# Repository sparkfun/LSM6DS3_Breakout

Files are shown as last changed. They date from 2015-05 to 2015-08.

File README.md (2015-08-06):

SparkFun <PRODUCT NAME>
========================================

LSM6DS3 Breakout

[*LSM6DS3 Breakout (SEN-13339)*](https://www.sparkfun.com/products/13339)

The LSM6DS3 Breakout board allows easy connection to the LSM6DS3.

The LSM6DS3 is a accelerometer, gyroscope, and temperature sensor with embedded functions targeted at cellphones.  It can do high sample rates and includes an 8kB FIFO buffer for burst reads.

Repository Contents
-------------------

* **/Documentation** - Data sheets, additional product information
* **/Hardware** - Eagle design files (.brd, .sch)
* **/Libraries** - Libraries for use with the LSM6DS3 Breakout
* **/Production** - Production panel files (.brd)

Documentation
--------------
* **[Library](https://github.com/sparkfun/SparkFun_LSM6DS3_Arduino_Library)** - C++ library for the LSM6DS3 Breakout.
* **[Hookup Guide](https://learn.sparkfun.com/tutorials/lsm6ds3-breakout-hookup-guide)** - Basic hookup guide for the LSM6DS3 Breakout.

Product Versions
----------------
* [SEN-13339](https://www.sparkfun.com/products/13339)- LSM6DS3 Breakout board

Version History
---------------
* [V_1.0.0](https://github.com/sparkfun/LSM6DS3_Breakout/releases/tag/V_1.0.0) - Initial product release repository
* [V_0.3.0](https://github.com/sparkfun/LSM6DS3_Breakout/releases/tag/V_0.3.0) - HW version 0.3 release

License Information
-------------------

This product is _**open source**_! 

Please review the LICENSE.md file for license information. 

If you have any questions or concerns on licensing, please contact techsupport@sparkfun.com.

Distributed as-is; no warranty is given.

- Your friends at SparkFun.

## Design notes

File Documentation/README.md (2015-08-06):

SparkFun Documentation
=======================

File List
---------

* AN4650_DM00157511.pdf - LSM6DS3 application note
* class diagrams.odg - src class diagrams
* class diagrams.pdf - export class diagrams
* DM00133076.pdf - LSM6DS3 datasheet
* Layout_CD00134799.pdf LSM6DS3 footprint information
* README.md - This file
* Test Plan.odt - description of things to test before release
* Test Record.odt - Results and findings of HW test

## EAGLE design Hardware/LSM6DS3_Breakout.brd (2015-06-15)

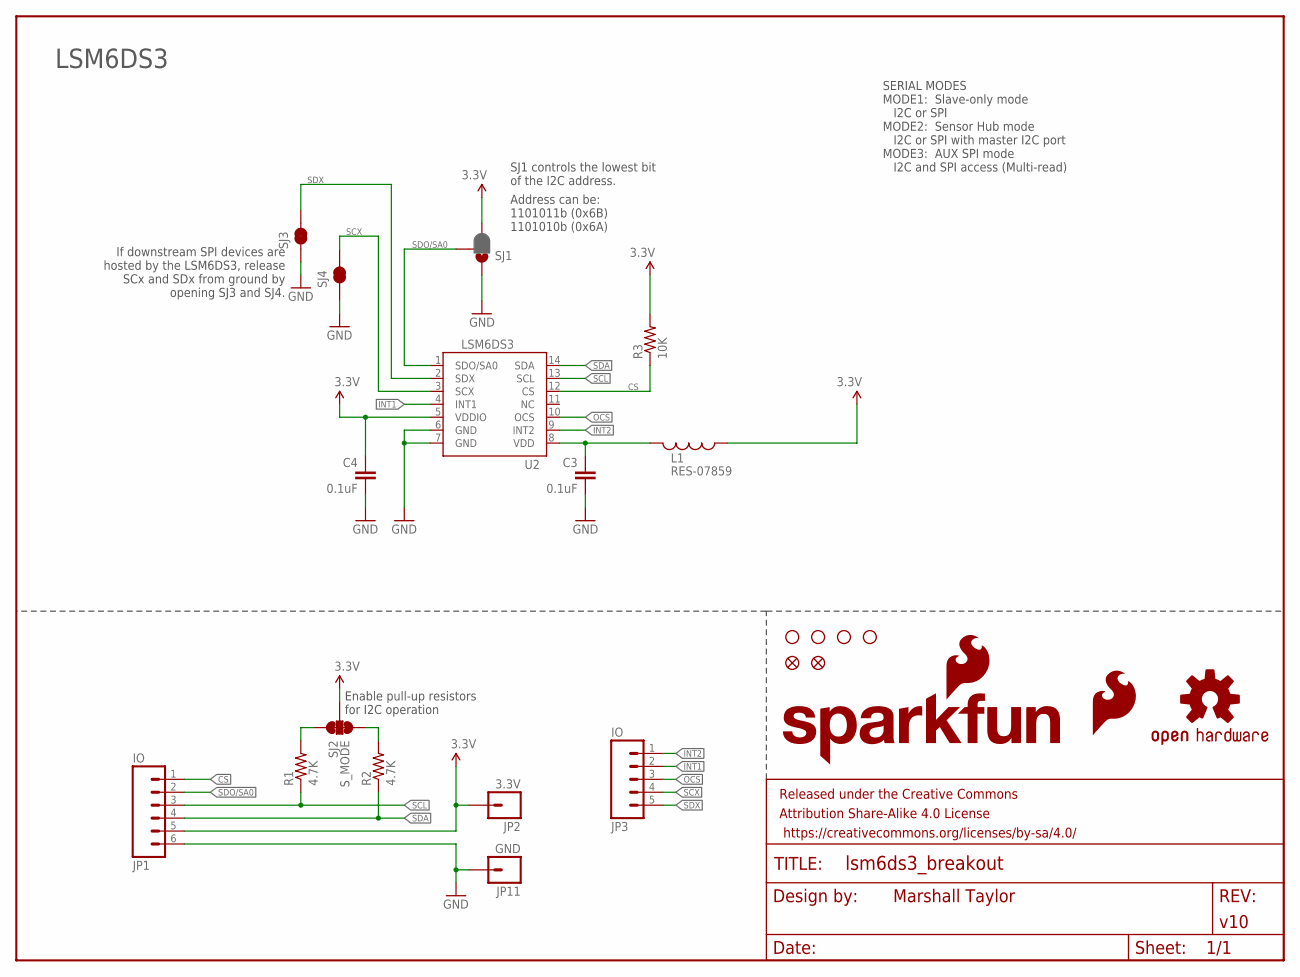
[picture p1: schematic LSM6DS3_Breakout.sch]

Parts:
C3, C4: 0.1uF; 0603-CAP
FID1, FID2: FIDUCIAL1X2; FIDUCIAL-1X2
FRAME1: FRAME-LETTER; CREATIVE_COMMONS
JP1: IO; 1X06_NO_SILK_YES_STOP
JP2: 3.3V; 1X01_NO_SILK
JP3: IO; 1X05
JP11: GND; 1X01_NO_SILK
L1: RES-07859; 0603
LOGO1: SFE_LOGO_FLAME.2_INCH; SFE_LOGO_FLAME_.2
LOGO2: OSHW-LOGOS; OSHW-LOGO-S
LOGO3: SFE_LOGO_NAME_FLAME.1_INCH; SFE_LOGO_NAME_FLAME_.1
R1, R2: 4.7K; 0603-RES
R3: 10K; 0603-RES
SJ1: JUMPER-PAD-3-2OF3_NC_BY_PASTE; PAD-JUMPER-3-2OF3_NC_BY_PASTE_YES_SILK_FULL_BOX
SJ2: S_MODE; PAD-JUMPER-3-3OF3_NC_BY_TRACE_YES_SILK_FULL_BOX
SJ3, SJ4: JUMPER-PAD-2-NC_BY_TRACE; PAD-JUMPER-2-NC_BY_TRACE_YES_SILK
STANDOFF1, STANDOFF2, STANDOFF3, STANDOFF4: STAND-OFF
U2: LSM6DS3; LGA14L_DOT_INDICATOR

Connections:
3.3V: C4.1, JP1.5, JP2.1, L1.1, R3.2, SJ1.3, SJ2.2, U2.5 (VDDIO)
CS: JP1.1, R3.1, U2.12 (CS)
GND: C3.2, C4.2, JP1.6, JP11.1, SJ1.1, SJ3.1, SJ4.1, U2.6 (GND), U2.7 (GND)
INT1: JP3.2, U2.4 (INT1)
INT2: JP3.1, U2.9 (INT2)
unnamed: R1.2, SJ2.1
unnamed: R2.2, SJ2.3
OCS: JP3.3, U2.10 (OCS)
SCL: JP1.3, R1.1, U2.13 (SCL)
SCX: JP3.4, SJ4.2, U2.3 (SCX)
SDA: JP1.4, R2.1, U2.14 (SDA)
SDO/SA0: JP1.2, SJ1.2, U2.1 (SDO/SA0)
SDX: JP3.5, SJ3.2, U2.2 (SDX)
VDD: C3.1, L1.2, U2.8 (VDD)

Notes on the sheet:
SJ1 controls the lowest bit of the I2C address.
LSM6DS3
If downstream SPI devices are hosted by the LSM6DS3, release SCx and SDx from ground by opening SJ3 and SJ4.
Address can be: 1101011b (0x6B) 1101010b (0x6A)
Enable pull-up resistors for I2C operation
SERIAL MODES MODE1: Slave-only mode I2C or SPI MODE2: Sensor Hub mode I2C or SPI with master I2C port MODE3: AUX SPI mode I2C and SPI access (Multi-read)

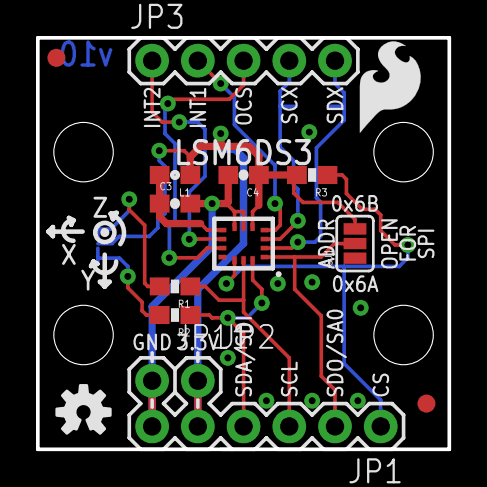
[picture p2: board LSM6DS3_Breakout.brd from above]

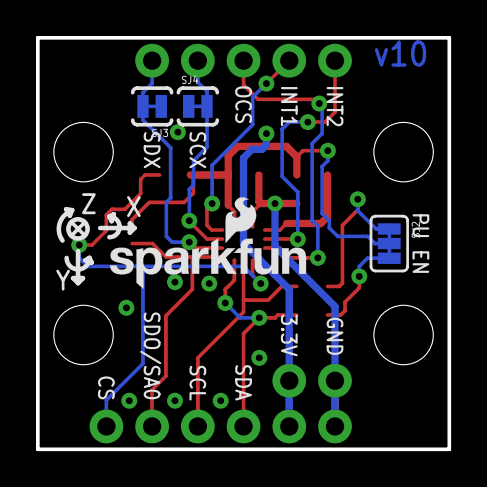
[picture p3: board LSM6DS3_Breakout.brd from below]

Board: 2 copper layers, 22.9 x 22.9 mm, 25 parts (4 on the bottom side), 14 nets.

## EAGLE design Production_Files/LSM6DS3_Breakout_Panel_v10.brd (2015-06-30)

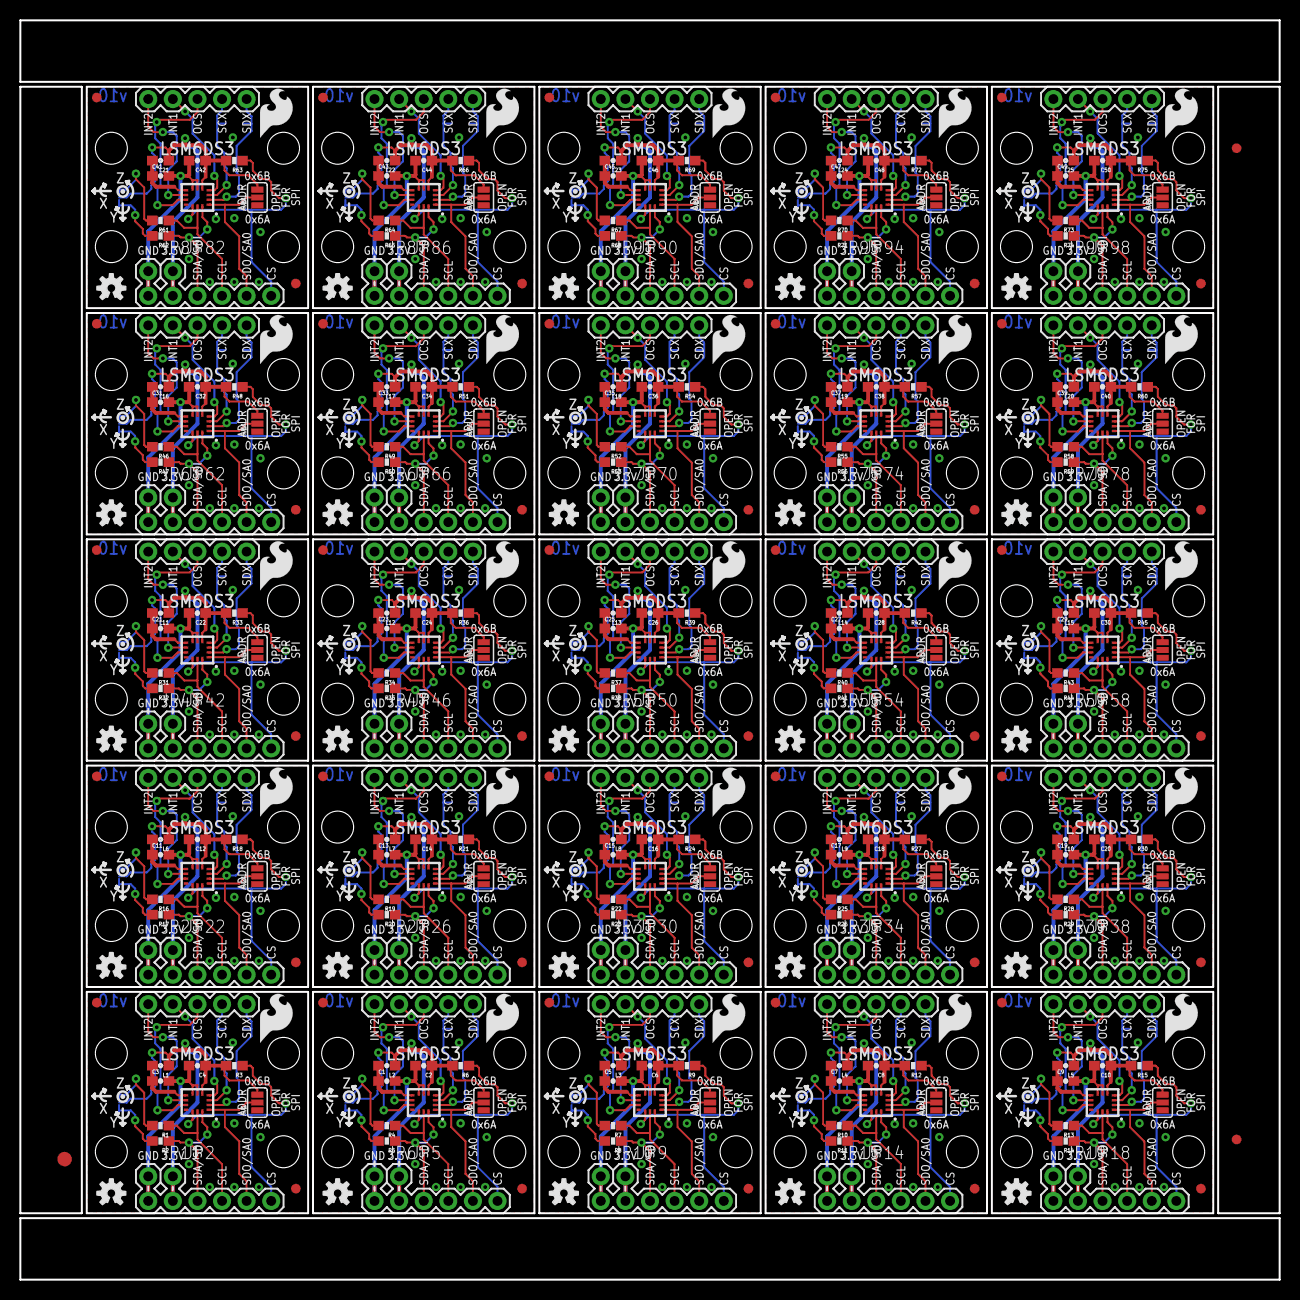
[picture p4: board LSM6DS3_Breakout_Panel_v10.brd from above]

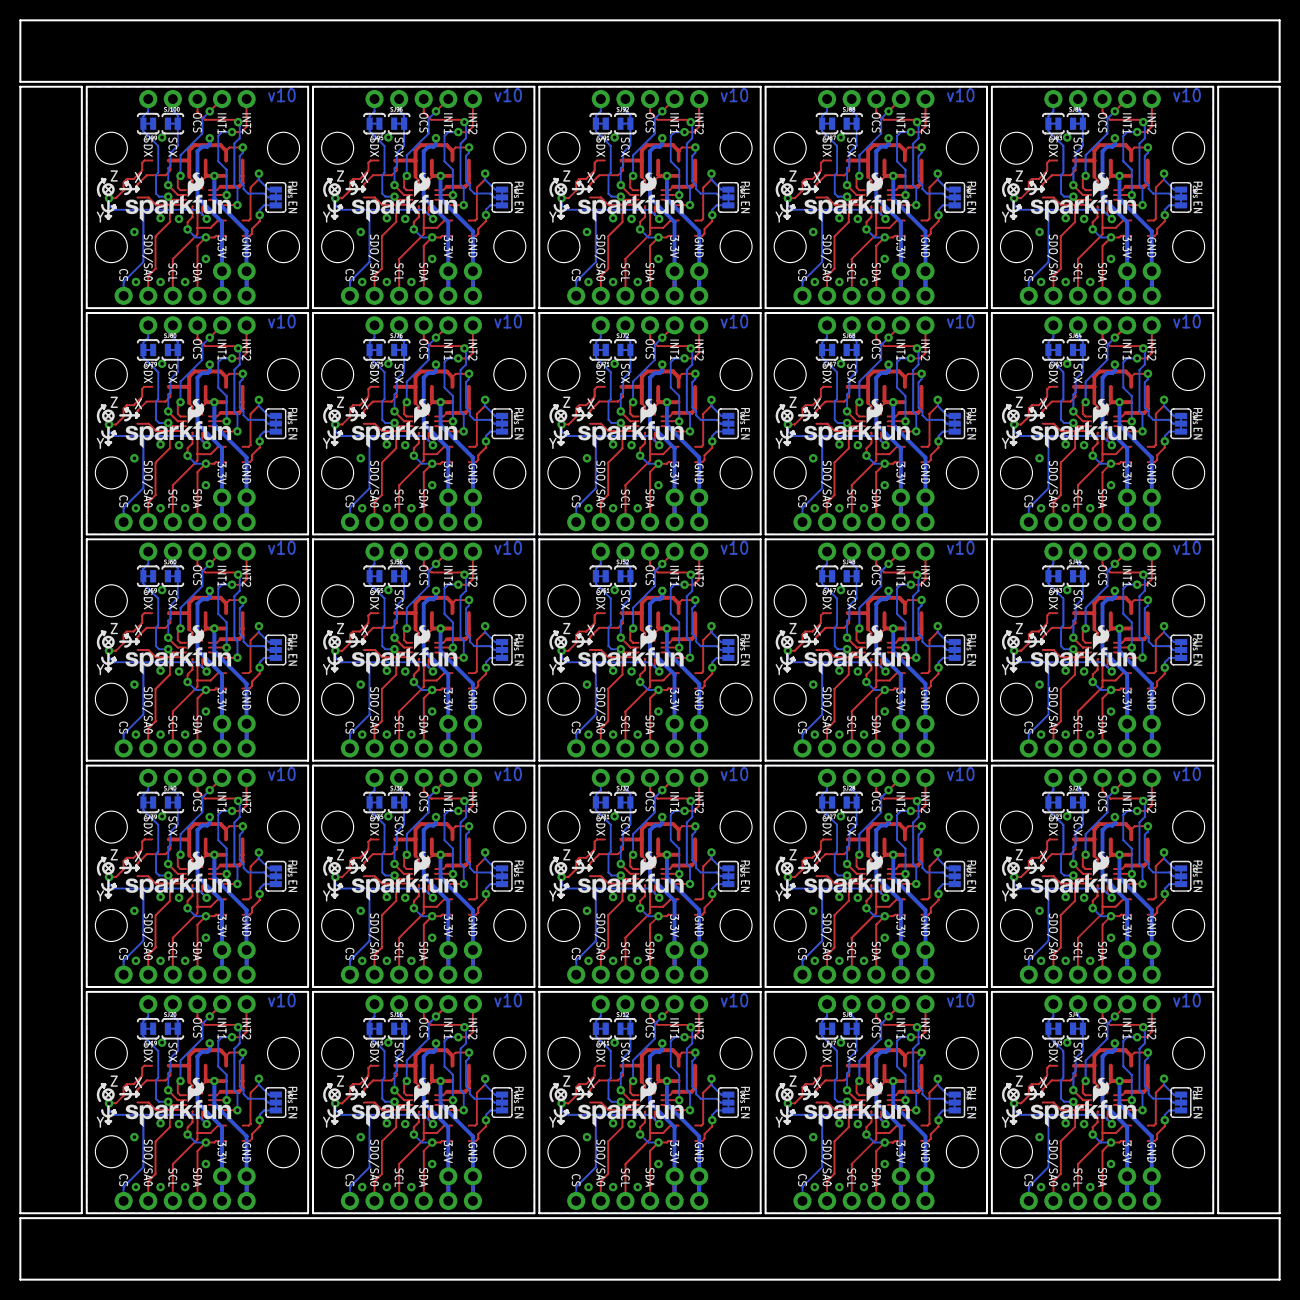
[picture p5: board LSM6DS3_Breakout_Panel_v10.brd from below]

Board: 2 copper layers, 130.0 x 130.0 mm, 603 parts (100 on the bottom side), 350 nets.

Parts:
C1, C2, C3, C4, C5, C6, C7, C8, C9, C10, C11, C12, C13, C14, C15, C16, C17, C18, C19, C20, C21, C22, C23, C24, C25, C26, C27, C28, C29, C30, C31, C32, C33, C34, C35, C36, C37, C38, C39, C40, C41, C42, C43, C44, C45, C46, C47, C48, C49, C50: 0.1uF; 0603-CAP
E$1: FIDUCIAL-1.5X3
E$6, E$7: FIDUCIAL-1X2
FID1, FID2, FID3, FID4, FID5, FID6, FID7, FID8, FID9, FID10, FID11, FID12, FID13, FID14, FID15, FID16, FID17, FID18, FID19, FID20, FID21, FID22, FID23, FID24, FID25, FID26, FID27, FID28, FID29, FID30, FID31, FID32, FID33, FID34, FID35, FID36, FID37, FID38, FID39, FID40, FID41, FID42, FID43, FID44, FID45, FID46, FID47, FID48, FID49, FID50: FIDUCIAL1X2; FIDUCIAL-1X2
JP1, JP4, JP8, JP13, JP17, JP21, JP25, JP29, JP33, JP37, JP41, JP45, JP49, JP53, JP57, JP61, JP65, JP69, JP73, JP77, JP81, JP85, JP89, JP93, JP97: IO; 1X06_NO_SILK_YES_STOP
JP2, JP5, JP9, JP14, JP18, JP22, JP26, JP30, JP34, JP38, JP42, JP46, JP50, JP54, JP58, JP62, JP66, JP70, JP74, JP78, JP82, JP86, JP90, JP94, JP98: 3.3V; 1X01_NO_SILK
JP3, JP7, JP12, JP16, JP20, JP24, JP28, JP32, JP36, JP40, JP44, JP48, JP52, JP56, JP60, JP64, JP68, JP72, JP76, JP80, JP84, JP88, JP92, JP96, JP100: IO; 1X05
JP6, JP10, JP11, JP15, JP19, JP23, JP27, JP31, JP35, JP39, JP43, JP47, JP51, JP55, JP59, JP63, JP67, JP71, JP75, JP79, JP83, JP87, JP91, JP95, JP99: GND; 1X01_NO_SILK
L1, L2, L3, L4, L5, L6, L7, L8, L9, L10, L11, L12, L13, L14, L15, L16, L17, L18, L19, L20, L21, L22, L23, L24, L25: RES-07859; 0603
LOGO1, LOGO4, LOGO7, LOGO10, LOGO13, LOGO16, LOGO19, LOGO22, LOGO25, LOGO28, LOGO31, LOGO34, LOGO37, LOGO40, LOGO43, LOGO46, LOGO49, LOGO52, LOGO55, LOGO58, LOGO61, LOGO64, LOGO67, LOGO70, LOGO73: SFE_LOGO_FLAME.2_INCH; SFE_LOGO_FLAME_.2
LOGO2, LOGO5, LOGO8, LOGO11, LOGO14, LOGO17, LOGO20, LOGO23, LOGO26, LOGO29, LOGO32, LOGO35, LOGO38, LOGO41, LOGO44, LOGO47, LOGO50, LOGO53, LOGO56, LOGO59, LOGO62, LOGO65, LOGO68, LOGO71, LOGO74: OSHW-LOGOS; OSHW-LOGO-S
LOGO3, LOGO6, LOGO9, LOGO12, LOGO15, LOGO18, LOGO21, LOGO24, LOGO27, LOGO30, LOGO33, LOGO36, LOGO39, LOGO42, LOGO45, LOGO48, LOGO51, LOGO54, LOGO57, LOGO60, LOGO63, LOGO66, LOGO69, LOGO72, LOGO75: SFE_LOGO_NAME_FLAME.1_INCH; SFE_LOGO_NAME_FLAME_.1
R1, R2, R4, R5, R7, R8, R10, R11, R13, R14, R16, R17, R19, R20, R22, R23, R25, R26, R28, R29, R31, R32, R34, R35, R37, R38, R40, R41, R43, R44, R46, R47, R49, R50, R52, R53, R55, R56, R58, R59, R61, R62, R64, R65, R67, R68, R70, R71, R73, R74: 4.7K; 0603-RES
R3, R6, R9, R12, R15, R18, R21, R24, R27, R30, R33, R36, R39, R42, R45, R48, R51, R54, R57, R60, R63, R66, R69, R72, R75: 10K; 0603-RES
SJ1, SJ5, SJ9, SJ13, SJ17, SJ21, SJ25, SJ29, SJ33, SJ37, SJ41, SJ45, SJ49, SJ53, SJ57, SJ61, SJ65, SJ69, SJ73, SJ77, SJ81, SJ85, SJ89, SJ93, SJ97: PAD-JUMPER-3-2OF3_NC_BY_PASTE_YES_SILK_FULL_BOX
SJ2, SJ6, SJ10, SJ14, SJ18, SJ22, SJ26, SJ30, SJ34, SJ38, SJ42, SJ46, SJ50, SJ54, SJ58, SJ62, SJ66, SJ70, SJ74, SJ78, SJ82, SJ86, SJ90, SJ94, SJ98: S_MODE; PAD-JUMPER-3-3OF3_NC_BY_TRACE_YES_SILK_FULL_BOX
SJ3, SJ4, SJ7, SJ8, SJ11, SJ12, SJ15, SJ16, SJ19, SJ20, SJ23, SJ24, SJ27, SJ28, SJ31, SJ32, SJ35, SJ36, SJ39, SJ40, SJ43, SJ44, SJ47, SJ48, SJ51, SJ52, SJ55, SJ56, SJ59, SJ60, SJ63, SJ64, SJ67, SJ68, SJ71, SJ72, SJ75, SJ76, SJ79, SJ80, SJ83, SJ84, SJ87, SJ88, SJ91, SJ92, SJ95, SJ96, SJ99, SJ100: JUMPER-PAD-2-NC_BY_TRACE; PAD-JUMPER-2-NC_BY_TRACE_YES_SILK
STANDOFF1, STANDOFF2, STANDOFF3, STANDOFF4, STANDOFF5, STANDOFF6, STANDOFF7, STANDOFF8, STANDOFF9, STANDOFF10, STANDOFF11, STANDOFF12, STANDOFF13, STANDOFF14, STANDOFF15, STANDOFF16, STANDOFF17, STANDOFF18, STANDOFF19, STANDOFF20, STANDOFF21, STANDOFF22, STANDOFF23, STANDOFF24, STANDOFF25, STANDOFF26, STANDOFF27, STANDOFF28, STANDOFF29, STANDOFF30, STANDOFF31, STANDOFF32, STANDOFF33, STANDOFF34, STANDOFF35, STANDOFF36, STANDOFF37, STANDOFF38, STANDOFF39, STANDOFF40, STANDOFF41, STANDOFF42, STANDOFF43, STANDOFF44, STANDOFF45, STANDOFF46, STANDOFF47, STANDOFF48, STANDOFF49, STANDOFF50, STANDOFF51, STANDOFF52, STANDOFF53, STANDOFF54, STANDOFF55, STANDOFF56, STANDOFF57, STANDOFF58, STANDOFF59, STANDOFF60, STANDOFF61, STANDOFF62, STANDOFF63, STANDOFF64, STANDOFF65, STANDOFF66, STANDOFF67, STANDOFF68, STANDOFF69, STANDOFF70, STANDOFF71, STANDOFF72, STANDOFF73, STANDOFF74, STANDOFF75, STANDOFF76, STANDOFF77, STANDOFF78, STANDOFF79, STANDOFF80, STANDOFF81, STANDOFF82, STANDOFF83, STANDOFF84, STANDOFF85, STANDOFF86, STANDOFF87, STANDOFF88, STANDOFF89, STANDOFF90, STANDOFF91, STANDOFF92, STANDOFF93, STANDOFF94, STANDOFF95, STANDOFF96, STANDOFF97, STANDOFF98, STANDOFF99, STANDOFF100: STAND-OFF
U1, U2, U3, U4, U5, U6, U7, U8, U9, U10, U11, U12, U13, U14, U15, U16, U17, U18, U19, U20, U21, U22, U23, U24, U25: LSM6DS3; LGA14L_DOT_INDICATOR

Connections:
3.3V: C4.1, JP1.5, JP2.1, L1.1, R3.2, SJ1.3, SJ2.2, U2.5
3.3V1: C2.1, JP4.5, JP5.1, L2.1, R6.2, SJ5.3, SJ6.2, U1.5
3.3V2: C6.1, JP8.5, JP9.1, L3.1, R9.2, SJ9.3, SJ10.2, U3.5
3.3V3: C8.1, JP13.5, JP14.1, L4.1, R12.2, SJ13.3, SJ14.2, U4.5
3.3V4: C10.1, JP17.5, JP18.1, L5.1, R15.2, SJ17.3, SJ18.2, U5.5
3.3V5: C12.1, JP21.5, JP22.1, L6.1, R18.2, SJ21.3, SJ22.2, U6.5
3.3V6: C14.1, JP25.5, JP26.1, L7.1, R21.2, SJ25.3, SJ26.2, U7.5
3.3V7: C16.1, JP29.5, JP30.1, L8.1, R24.2, SJ29.3, SJ30.2, U8.5
3.3V8: C18.1, JP33.5, JP34.1, L9.1, R27.2, SJ33.3, SJ34.2, U9.5
3.3V9: C20.1, JP37.5, JP38.1, L10.1, R30.2, SJ37.3, SJ38.2, U10.5
3.3V10: C22.1, JP41.5, JP42.1, L11.1, R33.2, SJ41.3, SJ42.2, U11.5
3.3V11: C24.1, JP45.5, JP46.1, L12.1, R36.2, SJ45.3, SJ46.2, U12.5
3.3V12: C26.1, JP49.5, JP50.1, L13.1, R39.2, SJ49.3, SJ50.2, U13.5
3.3V13: C28.1, JP53.5, JP54.1, L14.1, R42.2, SJ53.3, SJ54.2, U14.5
3.3V14: C30.1, JP57.5, JP58.1, L15.1, R45.2, SJ57.3, SJ58.2, U15.5
3.3V15: C32.1, JP61.5, JP62.1, L16.1, R48.2, SJ61.3, SJ62.2, U16.5
3.3V16: C34.1, JP65.5, JP66.1, L17.1, R51.2, SJ65.3, SJ66.2, U17.5
3.3V17: C36.1, JP69.5, JP70.1, L18.1, R54.2, SJ69.3, SJ70.2, U18.5
3.3V18: C38.1, JP73.5, JP74.1, L19.1, R57.2, SJ73.3, SJ74.2, U19.5
3.3V19: C40.1, JP77.5, JP78.1, L20.1, R60.2, SJ77.3, SJ78.2, U20.5
3.3V20: C42.1, JP81.5, JP82.1, L21.1, R63.2, SJ81.3, SJ82.2, U21.5
3.3V21: C44.1, JP85.5, JP86.1, L22.1, R66.2, SJ85.3, SJ86.2, U22.5
3.3V22: C46.1, JP89.5, JP90.1, L23.1, R69.2, SJ89.3, SJ90.2, U23.5
3.3V23: C48.1, JP93.5, JP94.1, L24.1, R72.2, SJ93.3, SJ94.2, U24.5
3.3V24: C50.1, JP97.5, JP98.1, L25.1, R75.2, SJ97.3, SJ98.2, U25.5
CS: JP1.1, R3.1, U2.12
CS1: JP4.1, R6.1, U1.12
CS2: JP8.1, R9.1, U3.12
CS3: JP13.1, R12.1, U4.12
CS4: JP17.1, R15.1, U5.12
CS5: JP21.1, R18.1, U6.12
CS6: JP25.1, R21.1, U7.12
CS7: JP29.1, R24.1, U8.12
CS8: JP33.1, R27.1, U9.12
CS9: JP37.1, R30.1, U10.12
CS10: JP41.1, R33.1, U11.12
CS11: JP45.1, R36.1, U12.12
CS12: JP49.1, R39.1, U13.12
CS13: JP53.1, R42.1, U14.12
CS14: JP57.1, R45.1, U15.12
CS15: JP61.1, R48.1, U16.12
CS16: JP65.1, R51.1, U17.12
CS17: JP69.1, R54.1, U18.12
CS18: JP73.1, R57.1, U19.12
CS19: JP77.1, R60.1, U20.12
CS20: JP81.1, R63.1, U21.12
CS21: JP85.1, R66.1, U22.12
CS22: JP89.1, R69.1, U23.12
CS23: JP93.1, R72.1, U24.12
CS24: JP97.1, R75.1, U25.12
GND: C3.2, C4.2, JP1.6, JP11.1, SJ1.1, SJ3.1, SJ4.1, U2.6, U2.7
GND1: C1.2, C2.2, JP4.6, JP6.1, SJ5.1, SJ7.1, SJ8.1, U1.6, U1.7
GND2: C5.2, C6.2, JP8.6, JP10.1, SJ9.1, SJ11.1, SJ12.1, U3.6, U3.7
GND3: C7.2, C8.2, JP13.6, JP15.1, SJ13.1, SJ15.1, SJ16.1, U4.6, U4.7
GND4: C9.2, C10.2, JP17.6, JP19.1, SJ17.1, SJ19.1, SJ20.1, U5.6, U5.7
GND5: C11.2, C12.2, JP21.6, JP23.1, SJ21.1, SJ23.1, SJ24.1, U6.6, U6.7
GND6: C13.2, C14.2, JP25.6, JP27.1, SJ25.1, SJ27.1, SJ28.1, U7.6, U7.7
GND7: C15.2, C16.2, JP29.6, JP31.1, SJ29.1, SJ31.1, SJ32.1, U8.6, U8.7
GND8: C17.2, C18.2, JP33.6, JP35.1, SJ33.1, SJ35.1, SJ36.1, U9.6, U9.7
GND9: C19.2, C20.2, JP37.6, JP39.1, SJ37.1, SJ39.1, SJ40.1, U10.6, U10.7
GND10: C21.2, C22.2, JP41.6, JP43.1, SJ41.1, SJ43.1, SJ44.1, U11.6, U11.7
GND11: C23.2, C24.2, JP45.6, JP47.1, SJ45.1, SJ47.1, SJ48.1, U12.6, U12.7
GND12: C25.2, C26.2, JP49.6, JP51.1, SJ49.1, SJ51.1, SJ52.1, U13.6, U13.7
GND13: C27.2, C28.2, JP53.6, JP55.1, SJ53.1, SJ55.1, SJ56.1, U14.6, U14.7
GND14: C29.2, C30.2, JP57.6, JP59.1, SJ57.1, SJ59.1, SJ60.1, U15.6, U15.7
GND15: C31.2, C32.2, JP61.6, JP63.1, SJ61.1, SJ63.1, SJ64.1, U16.6, U16.7
GND16: C33.2, C34.2, JP65.6, JP67.1, SJ65.1, SJ67.1, SJ68.1, U17.6, U17.7
GND17: C35.2, C36.2, JP69.6, JP71.1, SJ69.1, SJ71.1, SJ72.1, U18.6, U18.7
GND18: C37.2, C38.2, JP73.6, JP75.1, SJ73.1, SJ75.1, SJ76.1, U19.6, U19.7
GND19: C39.2, C40.2, JP77.6, JP79.1, SJ77.1, SJ79.1, SJ80.1, U20.6, U20.7
GND20: C41.2, C42.2, JP81.6, JP83.1, SJ81.1, SJ83.1, SJ84.1, U21.6, U21.7
GND21: C43.2, C44.2, JP85.6, JP87.1, SJ85.1, SJ87.1, SJ88.1, U22.6, U22.7
GND22: C45.2, C46.2, JP89.6, JP91.1, SJ89.1, SJ91.1, SJ92.1, U23.6, U23.7
GND23: C47.2, C48.2, JP93.6, JP95.1, SJ93.1, SJ95.1, SJ96.1, U24.6, U24.7
GND24: C49.2, C50.2, JP97.6, JP99.1, SJ97.1, SJ99.1, SJ100.1, U25.6, U25.7
INT1: JP3.2, U2.4
INT2: JP3.1, U2.9
INT3: JP7.2, U1.4
INT4: JP7.1, U1.9
INT5: JP12.2, U3.4
INT6: JP12.1, U3.9
INT7: JP16.2, U4.4
INT8: JP16.1, U4.9
INT9: JP20.2, U5.4
INT10: JP20.1, U5.9
INT11: JP24.2, U6.4
INT12: JP24.1, U6.9
INT13: JP28.2, U7.4
INT14: JP28.1, U7.9
INT15: JP32.2, U8.4
INT16: JP32.1, U8.9
INT17: JP36.2, U9.4
INT18: JP36.1, U9.9
INT19: JP40.2, U10.4
INT20: JP40.1, U10.9
INT21: JP44.2, U11.4
INT22: JP44.1, U11.9
INT23: JP48.2, U12.4
INT24: JP48.1, U12.9
INT25: JP52.2, U13.4
INT26: JP52.1, U13.9
INT27: JP56.2, U14.4
INT28: JP56.1, U14.9
INT29: JP60.2, U15.4
INT30: JP60.1, U15.9
INT31: JP64.2, U16.4
INT32: JP64.1, U16.9
INT33: JP68.2, U17.4
INT34: JP68.1, U17.9
INT35: JP72.2, U18.4
INT36: JP72.1, U18.9
INT37: JP76.2, U19.4
INT38: JP76.1, U19.9
INT39: JP80.2, U20.4
INT40: JP80.1, U20.9
INT41: JP84.2, U21.4
INT42: JP84.1, U21.9
INT43: JP88.2, U22.4
INT44: JP88.1, U22.9
INT45: JP92.2, U23.4
INT46: JP92.1, U23.9
INT47: JP96.2, U24.4
INT48: JP96.1, U24.9
INT49: JP100.2, U25.4
INT50: JP100.1, U25.9
unnamed: R4.2, SJ6.1
unnamed: R5.2, SJ6.3
unnamed: R7.2, SJ10.1
unnamed: R8.2, SJ10.3
unnamed: R1.2, SJ2.1
unnamed: R2.2, SJ2.3
unnamed: R10.2, SJ14.1
unnamed: R11.2, SJ14.3
unnamed: R13.2, SJ18.1
unnamed: R14.2, SJ18.3
unnamed: R16.2, SJ22.1
unnamed: R17.2, SJ22.3
unnamed: R19.2, SJ26.1
unnamed: R20.2, SJ26.3
unnamed: R22.2, SJ30.1
unnamed: R23.2, SJ30.3
unnamed: R25.2, SJ34.1
unnamed: R26.2, SJ34.3
unnamed: R28.2, SJ38.1
unnamed: R29.2, SJ38.3
unnamed: R31.2, SJ42.1
unnamed: R32.2, SJ42.3
unnamed: R34.2, SJ46.1
unnamed: R35.2, SJ46.3
unnamed: R37.2, SJ50.1
unnamed: R38.2, SJ50.3
unnamed: R40.2, SJ54.1
unnamed: R41.2, SJ54.3
unnamed: R43.2, SJ58.1
unnamed: R44.2, SJ58.3
unnamed: R46.2, SJ62.1
unnamed: R47.2, SJ62.3
unnamed: R49.2, SJ66.1
unnamed: R50.2, SJ66.3
unnamed: R52.2, SJ70.1
unnamed: R53.2, SJ70.3
unnamed: R55.2, SJ74.1
unnamed: R56.2, SJ74.3
unnamed: R58.2, SJ78.1
unnamed: R59.2, SJ78.3
unnamed: R61.2, SJ82.1
unnamed: R62.2, SJ82.3
unnamed: R64.2, SJ86.1
unnamed: R65.2, SJ86.3
unnamed: R67.2, SJ90.1
unnamed: R68.2, SJ90.3
unnamed: R70.2, SJ94.1
unnamed: R71.2, SJ94.3
unnamed: R73.2, SJ98.1
unnamed: R74.2, SJ98.3
OCS: JP3.3, U2.10
OCS1: JP7.3, U1.10
OCS2: JP12.3, U3.10
OCS3: JP16.3, U4.10
OCS4: JP20.3, U5.10
OCS5: JP24.3, U6.10
OCS6: JP28.3, U7.10
OCS7: JP32.3, U8.10
OCS8: JP36.3, U9.10
OCS9: JP40.3, U10.10
OCS10: JP44.3, U11.10
OCS11: JP48.3, U12.10
OCS12: JP52.3, U13.10
OCS13: JP56.3, U14.10
OCS14: JP60.3, U15.10
OCS15: JP64.3, U16.10
OCS16: JP68.3, U17.10
OCS17: JP72.3, U18.10
OCS18: JP76.3, U19.10
OCS19: JP80.3, U20.10
OCS20: JP84.3, U21.10
OCS21: JP88.3, U22.10
OCS22: JP92.3, U23.10
OCS23: JP96.3, U24.10
OCS24: JP100.3, U25.10
SCL: JP1.3, R1.1, U2.13
SCL1: JP4.3, R4.1, U1.13
SCL2: JP8.3, R7.1, U3.13
SCL3: JP13.3, R10.1, U4.13
SCL4: JP17.3, R13.1, U5.13
SCL5: JP21.3, R16.1, U6.13
SCL6: JP25.3, R19.1, U7.13
SCL7: JP29.3, R22.1, U8.13
SCL8: JP33.3, R25.1, U9.13
SCL9: JP37.3, R28.1, U10.13
SCL10: JP41.3, R31.1, U11.13
SCL11: JP45.3, R34.1, U12.13
SCL12: JP49.3, R37.1, U13.13
SCL13: JP53.3, R40.1, U14.13
SCL14: JP57.3, R43.1, U15.13
SCL15: JP61.3, R46.1, U16.13
SCL16: JP65.3, R49.1, U17.13
SCL17: JP69.3, R52.1, U18.13
SCL18: JP73.3, R55.1, U19.13
SCL19: JP77.3, R58.1, U20.13
SCL20: JP81.3, R61.1, U21.13
SCL21: JP85.3, R64.1, U22.13
SCL22: JP89.3, R67.1, U23.13
SCL23: JP93.3, R70.1, U24.13
SCL24: JP97.3, R73.1, U25.13
SCX: JP3.4, SJ4.2, U2.3
SCX1: JP7.4, SJ8.2, U1.3
SCX2: JP12.4, SJ12.2, U3.3
SCX3: JP16.4, SJ16.2, U4.3
SCX4: JP20.4, SJ20.2, U5.3
SCX5: JP24.4, SJ24.2, U6.3
SCX6: JP28.4, SJ28.2, U7.3
SCX7: JP32.4, SJ32.2, U8.3
SCX8: JP36.4, SJ36.2, U9.3
SCX9: JP40.4, SJ40.2, U10.3
SCX10: JP44.4, SJ44.2, U11.3
SCX11: JP48.4, SJ48.2, U12.3
SCX12: JP52.4, SJ52.2, U13.3
SCX13: JP56.4, SJ56.2, U14.3
SCX14: JP60.4, SJ60.2, U15.3
SCX15: JP64.4, SJ64.2, U16.3
SCX16: JP68.4, SJ68.2, U17.3
SCX17: JP72.4, SJ72.2, U18.3
SCX18: JP76.4, SJ76.2, U19.3
SCX19: JP80.4, SJ80.2, U20.3
SCX20: JP84.4, SJ84.2, U21.3
SCX21: JP88.4, SJ88.2, U22.3
SCX22: JP92.4, SJ92.2, U23.3
SCX23: JP96.4, SJ96.2, U24.3
SCX24: JP100.4, SJ100.2, U25.3
SDA: JP1.4, R2.1, U2.14
SDA1: JP4.4, R5.1, U1.14
SDA2: JP8.4, R8.1, U3.14
SDA3: JP13.4, R11.1, U4.14
SDA4: JP17.4, R14.1, U5.14
SDA5: JP21.4, R17.1, U6.14
SDA6: JP25.4, R20.1, U7.14
SDA7: JP29.4, R23.1, U8.14
SDA8: JP33.4, R26.1, U9.14
SDA9: JP37.4, R29.1, U10.14
SDA10: JP41.4, R32.1, U11.14
SDA11: JP45.4, R35.1, U12.14
SDA12: JP49.4, R38.1, U13.14
SDA13: JP53.4, R41.1, U14.14
SDA14: JP57.4, R44.1, U15.14
SDA15: JP61.4, R47.1, U16.14
SDA16: JP65.4, R50.1, U17.14
SDA17: JP69.4, R53.1, U18.14
SDA18: JP73.4, R56.1, U19.14
SDA19: JP77.4, R59.1, U20.14
SDA20: JP81.4, R62.1, U21.14
SDA21: JP85.4, R65.1, U22.14
SDA22: JP89.4, R68.1, U23.14
SDA23: JP93.4, R71.1, U24.14
SDA24: JP97.4, R74.1, U25.14
SDO/SA0: JP1.2, SJ1.2, U2.1
SDO/SA1: JP4.2, SJ5.2, U1.1
SDO/SA2: JP8.2, SJ9.2, U3.1
SDO/SA3: JP13.2, SJ13.2, U4.1
SDO/SA4: JP17.2, SJ17.2, U5.1
SDO/SA5: JP21.2, SJ21.2, U6.1
SDO/SA6: JP25.2, SJ25.2, U7.1
SDO/SA7: JP29.2, SJ29.2, U8.1
SDO/SA8: JP33.2, SJ33.2, U9.1
SDO/SA9: JP37.2, SJ37.2, U10.1
SDO/SA10: JP41.2, SJ41.2, U11.1
SDO/SA11: JP45.2, SJ45.2, U12.1
SDO/SA12: JP49.2, SJ49.2, U13.1
SDO/SA13: JP53.2, SJ53.2, U14.1
SDO/SA14: JP57.2, SJ57.2, U15.1
SDO/SA15: JP61.2, SJ61.2, U16.1
SDO/SA16: JP65.2, SJ65.2, U17.1
SDO/SA17: JP69.2, SJ69.2, U18.1
SDO/SA18: JP73.2, SJ73.2, U19.1
SDO/SA19: JP77.2, SJ77.2, U20.1
SDO/SA20: JP81.2, SJ81.2, U21.1
SDO/SA21: JP85.2, SJ85.2, U22.1
SDO/SA22: JP89.2, SJ89.2, U23.1
SDO/SA23: JP93.2, SJ93.2, U24.1
SDO/SA24: JP97.2, SJ97.2, U25.1
SDX: JP3.5, SJ3.2, U2.2
SDX1: JP7.5, SJ7.2, U1.2
SDX2: JP12.5, SJ11.2, U3.2
SDX3: JP16.5, SJ15.2, U4.2
SDX4: JP20.5, SJ19.2, U5.2
SDX5: JP24.5, SJ23.2, U6.2
SDX6: JP28.5, SJ27.2, U7.2
SDX7: JP32.5, SJ31.2, U8.2
SDX8: JP36.5, SJ35.2, U9.2
SDX9: JP40.5, SJ39.2, U10.2
SDX10: JP44.5, SJ43.2, U11.2
SDX11: JP48.5, SJ47.2, U12.2
SDX12: JP52.5, SJ51.2, U13.2
SDX13: JP56.5, SJ55.2, U14.2
SDX14: JP60.5, SJ59.2, U15.2
SDX15: JP64.5, SJ63.2, U16.2
SDX16: JP68.5, SJ67.2, U17.2
SDX17: JP72.5, SJ71.2, U18.2
SDX18: JP76.5, SJ75.2, U19.2
SDX19: JP80.5, SJ79.2, U20.2
SDX20: JP84.5, SJ83.2, U21.2
SDX21: JP88.5, SJ87.2, U22.2
SDX22: JP92.5, SJ91.2, U23.2
SDX23: JP96.5, SJ95.2, U24.2
SDX24: JP100.5, SJ99.2, U25.2
VDD: C3.1, L1.2, U2.8
VDD1: C1.1, L2.2, U1.8
VDD2: C5.1, L3.2, U3.8
VDD3: C7.1, L4.2, U4.8
VDD4: C9.1, L5.2, U5.8
VDD5: C11.1, L6.2, U6.8
VDD6: C13.1, L7.2, U7.8
VDD7: C15.1, L8.2, U8.8
VDD8: C17.1, L9.2, U9.8
VDD9: C19.1, L10.2, U10.8
VDD10: C21.1, L11.2, U11.8
VDD11: C23.1, L12.2, U12.8
VDD12: C25.1, L13.2, U13.8
VDD13: C27.1, L14.2, U14.8
VDD14: C29.1, L15.2, U15.8
VDD15: C31.1, L16.2, U16.8
VDD16: C33.1, L17.2, U17.8
VDD17: C35.1, L18.2, U18.8
VDD18: C37.1, L19.2, U19.8
VDD19: C39.1, L20.2, U20.8
VDD20: C41.1, L21.2, U21.8
VDD21: C43.1, L22.2, U22.8
VDD22: C45.1, L23.2, U23.8
VDD23: C47.1, L24.2, U24.8
VDD24: C49.1, L25.2, U25.8

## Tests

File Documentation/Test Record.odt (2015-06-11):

# Title

## Check polarity of silkscreen markings

The PCB has a silkscreen marking that depicts the coordenant system.

The straight arrows point to acceleration direction that results in positively measured acceleration.

The curved arrors are unclear. Use the right hand rule to determine rotation direction that measures as a positive rate of change.

Procedure:

1. Load the minimalist example.
2. Move the IMU throught the 6 axis.

Criteria:

1. Are the polarities correct? YES

## Check the signal integrity of the I2C lines

Procedure:

1. Socket EUT In breadboard
2. Fly wires to redboard using 6" ended cables (like in SIK)
3. Capture scopes shots of I2C signal and clock, running messages at fastest mode. (100kHz)
4. Capture scopes shots of I2C signal and clock with two I2C loads

Criteria:

1. Does the signal rise in a sufficiently small time? What is it? 480ns
2. Is the clock running at 100kHz YES
3. Does the signal signal rise and fall monotonicly? YES

Test Pictures:

Single I2C load

Dual I2C load

Rise Times

## Check the signal integrity of the SPI lines

Procedure:

1. Socket EUT In breadboard
2. Socket BOB-12009 level shifter into breadboard
3. Connect up power and 4 signal wires to the shifter with 1 inch wires.
4. Fly wires to redboard using 6" ended cables
5. Capture scopes shots of SPI messages at highest speed possible. Inspect between level shifter and EUT.

Criteria:

1. Is data changed on the falling edge? YES
2. Does the signal signal rise and fall monotonicly? YES
3. Does the signal shape look square? YES
4. What is the clock frequency measured? 4.032MHz

Test Pictures:

Message (READ op, addr 0x28 (First data reg), reading 0xFFE9, int16: -23

Zoom in, data changes on falling edge.

## Power Consumption

Procedure:

1. Measure the idling current consumption while connected to a 3.3v MCU
2. Measure the current consumption during fastest FIFO operation possible (SPI_MODE)

## Response to over-volt condition

This test is destructive, do it last

Procedure:

1. Operate the EUT at the hightest bus load possible and at 3.3v.
2. Step the supply voltage up while monitoring and recording current. As so as a runaway condition starts, remove power. If possible, vary the bus voltage with the supply voltage.
3. Run the I2C mode straight from a 5v arduino.
4. Run the SPI mode straight from a 5v arduino.

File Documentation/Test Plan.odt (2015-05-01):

# Type testing plan

## Code Things to verify

- Range config
- Data rate config
- Mode 1 SPI
- Mode 1 I2C
- Mode 1 I2C with 2 sensors
- Mode 2 SPI with 2 downstream sensors
- Mode 2 I2C with 2 downstream sensors
- Mode 3 reading from two Arduinos
- FIFO operation
- Wake on Threshold INT function
- Other INT functions

Things in bold are supported by the driver set, but other operation should be checked out, even if hacky.

## HW things to verify

- Silkscreen axes for polarity
- Power consumption

## Things to consider

- Calibration registers
- Zero (tare) ability

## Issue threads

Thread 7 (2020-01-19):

Orientation?

TheNitek, 2020-01-19:
Is it currently possible to get the orientation of the sensor (compared to the "boot" orientation) or do I need to calculate it myself by using the gyro values?

Closed 2020-01-29.

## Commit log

2015-03-25 Initial HW commit
    [LSM6DS3_Breakout.brd, LSM6DS3_Breakout.sch]
2015-03-25 ready for proto
    [LSM6DS3_Breakout.brd, LSM6DS3_Breakout.sch]
2015-03-25 Fixed pull-ups
    [LSM6DS3_Breakout.brd, LSM6DS3_Breakout.sch]
2015-03-26 Moved eagle project
    [LSM6DS3_Breakout.brd, LSM6DS3_Breakout.sch]
2015-03-26 Swapped choke
    [LSM6DS3_Breakout.brd, LSM6DS3_Breakout.sch]
2015-03-27 Fixed ripped up component
    [LSM6DS3_Breakout.brd]
2015-03-30 Switched pads for pins, grew board.
    [LSM6DS3_Breakout.brd, LSM6DS3_Breakout.sch]
2015-04-01 Corrected QC suggestions
    [LSM6DS3_Breakout.brd, LSM6DS3_Breakout.sch]
2015-04-01 Fixed erroneous floating silk text
    [LSM6DS3_Breakout.brd]
2015-04-16 Hollow I2C functions
2015-04-21 built arduino project
2015-04-24 SPI and I2C functional
2015-04-24 Re-organized file structure for Arduino IDE
2015-04-30 v03 commit
    [LSM6DS3_Breakout.brd, LSM6DS3_Breakout.sch]
2015-05-01 Fixed QC Issues
    [LSM6DS3_Breakout.brd, LSM6DS3_Breakout.sch]
2015-06-11 Fixed silk for redboards
    [LSM6DS3_Breakout.brd, LSM6DS3_Breakout.sch]
2015-06-15 Fixed Silk
    [LSM6DS3_Breakout.brd]
2015-06-30 created panel v10
    [LSM6DS3_Breakout_Panel_v10.brd]
2015-08-06 inserted new files
2015-08-06 Squashed 'Libraries/Arduino/' content from commit fdb8ef4
    git-subtree-dir: Libraries/Arduino
    git-subtree-split: fdb8ef44369df43f16a7f1419b3a912071b49a01
2015-08-06 Squashed 'Libraries/Arduino/' content from commit 79e3b6b
    git-subtree-split: 79e3b6b4ac0c7d8ae5783147f556e840cbd6f981
    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

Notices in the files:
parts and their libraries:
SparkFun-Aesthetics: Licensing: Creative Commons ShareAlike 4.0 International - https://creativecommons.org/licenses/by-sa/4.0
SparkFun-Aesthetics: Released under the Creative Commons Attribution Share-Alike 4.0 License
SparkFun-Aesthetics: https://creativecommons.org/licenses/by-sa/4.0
